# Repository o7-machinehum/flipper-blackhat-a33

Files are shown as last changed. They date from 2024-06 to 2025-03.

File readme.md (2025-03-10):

# Flipper Blackhat A33

The Flipper Blackhat is a Linux based Flipper addon that enables WiFi attacks. It uses an Allwinner A33, which is a quad-core SoC connected to 1Gb of RAM. The board has two USB2 ports, and one USB-C, which is connected to an FTDI.



## TODO (Next Board Rev)

    - [ ] TVS diodes on USB
    - [ ] Reset button
    - [ ] LED
    - [ ] Mounting holes for mech
    - [ ] Cost analasys

## License
The project is licensed under the Creative Commons (4.0 International License) Attribution—Noncommercial—Share Alike license. This allows sharing and adapting material for non-commercial purposes, provided credit is given to the creator and adaptations are shared under the same terms. The material can be used in any format with necessary technical modifications, but no warranties are provided. The license prohibits imposing additional restrictions and ensures the rights are irrevocable as long as the terms are followed.

Make boards for youself, make boards for your friends, but **please do not sell hundreds on them on Aliexpress**. I'm selling boards [here](shop.rootkitlabs.com), the money made here goes back into this project, and other alike open source projects!

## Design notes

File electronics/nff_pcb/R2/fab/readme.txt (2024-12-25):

Flipper Blackhat
--------
Size :	92 x 53
Layer : 4 Layers
Material : FR-4: TG150
Thickness : 1.6 mm
Min track/spacing : 4/4mil
Min hole size : 0.2mm
Solder mask : Black
Silkscreen : White
Edge connector : No
Surface finish : ENIG lead free
Via process : Tenting vias
Finished copper : 1 oz Cu (Inner Copper:1 oz)
Remove product No. : Yes

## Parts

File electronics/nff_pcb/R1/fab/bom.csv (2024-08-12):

Reference | Value | Footprint | Qty | DNP | MPN
C1,C2,C3,C4,C5,C27,C30,C31,C32,C33,C37,C38,C40,C42,C43,C48,C59,C64,C65,C66,C67,C68,C73,C74,C75,C76,C77,C78,C79,C80,C82,C85,C86,C87,C89,C90,C91,C92,C93,C100,C104 | 100nF | Capacitor_SMD:C_0402_1005Metric | 41 |  | CC0402KRX7R7BB104
C6,C9,C10,C11,C14,C15,C16,C17,C22,C23,C24,C25 | 22uF | Capacitor_SMD:C_0805_2012Metric | 12 |  | CL21A226MQQNNNE
C7,C12,C18,C20 | 10nF | Capacitor_SMD:C_0402_1005Metric | 4 |  | CL05B103KB5NNNC
C8,C13 | 450pF | Capacitor_SMD:C_0402_1005Metric | 2 |  | CL05B471KB5NNNC
C19,C21 | 5nF | Capacitor_SMD:C_0402_1005Metric | 2 |  | CC0402KRX7R9BB562
C26,C28 | 10uF | Capacitor_SMD:C_0805_2012Metric | 2 |  | GRM21BR70J106KE76L
C29,C99,C102,C103 | 10uF | Capacitor_SMD:C_0402_1005Metric | 4 |  | CL05A106MQ5NUNC
C34,C49,C50,C101 | 1uF | Capacitor_SMD:C_0402_1005Metric | 4 |  | CL05A105KO5NNNC
C35 | 0.22uF | Capacitor_SMD:C_0603_1608Metric | 1 |  | CC0402KRX7R7BB224
C41,C45,C46,C47 | 10uF | Capacitor_SMD:C_0603_1608Metric | 4 |  | LMK107BBJ106MALT
C53,C54,C55,C56,C69,C70,C94 | 22uF | Capacitor_SMD:C_0402_1005Metric | 7 |  | GRM158R60J226ME01D
C95,C96 | 10pF | Capacitor_SMD:C_0402_1005Metric | 2 |  | CC0402JRNPO9BN100
C97,C98 | 30pF | Capacitor_SMD:C_0402_1005Metric | 2 |  | CC0402JRNPO9BN300
J1 | Micro_SD_Card_Det_Hirose_DM3AT | Connector_Card:microSD_HC_Hirose_DM3AT-SF-PEJM5 | 1 |  | DM3AT-SF-PEJM5
J2,J3 | USB_A | Connector_USB:USB_A_Molex_105057_Vertical | 2 |  | 1050570001
J4 | Conn_01x08_Pin | Connector_PinHeader_2.54mm:PinHeader_1x08_P2.54mm_Horizontal | 1 |  | PH1RB-08-UA
J5 | USB_C_Receptacle_USB2.0_16P | Connector_USB:USB_C_Receptacle_GCT_USB4105-xx-A_16P_TopMnt_Horizontal | 1 |  | USB4105-GF-A-120
J6 | Conn_01x10_Pin | Connector_PinHeader_2.54mm:PinHeader_1x10_P2.54mm_Horizontal | 1 |  | PH1RB-10-UA
J7 | Conn_Coaxial | Connector_Coaxial:SMA_Amphenol_901-143_Horizontal | 1 |  | 901-143-6RFX
J8 | Conn_01x20_MountingPin | Connector_FFC-FPC:Hirose_FH12-20S-0.5SH_1x20-1MP_P0.50mm_Horizontal | 1 |  | FH12-20S-0.5SH(55)
L1,L2,L3,L4 | 1uH | Inductor_SMD:L_Coilcraft_XxL4020 | 4 |  | XAL4020-102ME
L5 | 120R@100MHz | Inductor_SMD:L_0603_1608Metric | 1 |  | BLM18KG121TN1D
L6 | 22uH | Inductor_SMD:L_1210_3225Metric | 1 |  | CBC3225T220MR
R1,R2,R4,R5 | 1k | Resistor_SMD:R_0402_1005Metric | 4 |  | 4-1879208-9
R3,R6 | 240R | Resistor_SMD:R_0402_1005Metric | 2 |  | 0402WGF2400TCE
R7 | 470k | Resistor_SMD:R_0402_1005Metric | 1 |  | RTT024703FTH
R8 | 150k | Resistor_SMD:R_0402_1005Metric | 1 |  | RC0402FR-07150KL
R9 | 330k | Resistor_SMD:R_0402_1005Metric | 1 |  | RC0402FR-07330KL
R10 | 120k | Resistor_SMD:R_0402_1005Metric | 1 |  | RTT021203FTH
R11 | 110k | Resistor_SMD:R_0402_1005Metric | 1 |  | RTT021103FTH
R12 | 160k | Resistor_SMD:R_0402_1005Metric | 1 |  | 0402WGF1603TCE
R13 | 82k | Resistor_SMD:R_0402_1005Metric | 1 |  | 0402WGF8202TCE
R14 | 220k | Resistor_SMD:R_0402_1005Metric | 1 |  | ERJPA2F2203X
R15,R16,R17,R18,R19,R26 | 0R | Resistor_SMD:R_0402_1005Metric | 6 |  | RC0402JR-070RL
R20 | 5R1 | Resistor_SMD:R_0402_1005Metric | 1 |  | RC0402JR-075R1L
R21,R30 | 10k | Resistor_SMD:R_0402_1005Metric | 2 |  | RC0402JR-0710KL
R22,R39 | 10k | Resistor_SMD:R_0402_1005Metric | 2 |  | RC0402FR-1310KL
R23,R24,R25,R41,R42 | 100k | Resistor_SMD:R_0402_1005Metric | 5 |  | RC0402FR-13100KL
R27,R28 | 22R | Resistor_SMD:R_0402_1005Metric | 2 |  | RC0402JR-0722RL
R29,R31 | 10M | Resistor_SMD:R_0402_1005Metric | 2 |  | 0402WGJ0106TCE
R32 | 200k | Resistor_SMD:R_0402_1005Metric | 1 |  | RC0402FR-07200KL
R33,R36 | 1k | Resistor_SMD:R_0402_1005Metric | 2 |  | RC0402FR-131KL
R35 | 0R | Resistor_SMD:R_0402_1005Metric | 1 |  | RC0402FR-130RL
R37 | 100K | Resistor_SMD:R_0402_1005Metric | 1 |  | RC0402FR-13100KL
R43,R44 | 5.6k | Resistor_SMD:R_0402_1005Metric | 2 |  | RC0402FR-135K6L
RN1,RN2 | 10k | Resistor_SMD:R_Array_Convex_4x0402 | 2 |  | 4D02WGJ0103TCE
U1 | AS4C512M16D3L-12BIN | AS4C512M16D3L:Alliance_Memory-AS4C512M16D3L-12BIN-0-0-IPC_A | 1 |  | AS4C512M16D3L-12BIN
U2 | A33 | A33_FP:Allwinner_Technology_Co.,_Ltd.-A33-0 | 1 |  | A33
U3,U4,U5,U6 | TPS62095RGTR | TI:TI_RTE_S-PWQFN-N16 | 4 |  | TPS62095RGTR
U7 | AP131-25 | Package_TO_SOT_SMD:SOT-23-5 | 1 |  | AP131-25
U8 | RTL8723DS | KiLib:RTL8723 | 1 |  | RTL8723DS
U9 | AP3036B | Package_TO_SOT_SMD:SOT-23-6 | 1 |  | AP3036B
U10 | CH340C | Package_SO:SOIC-16_3.9x9.9mm_P1.27mm | 1 |  | CH340C
Y1 | 24Mhz | Crystal:Crystal_SMD_Abracon_ABM8G-4Pin_3.2x2.5mm | 1 |  | ABM8G-24.000MHZ-18-D2Y-T
Y2 | 32.768khz | Abracon:Abracon-ABS05-0-0-MFG | 1 |  | ABS05-32.768KHZ-9-T

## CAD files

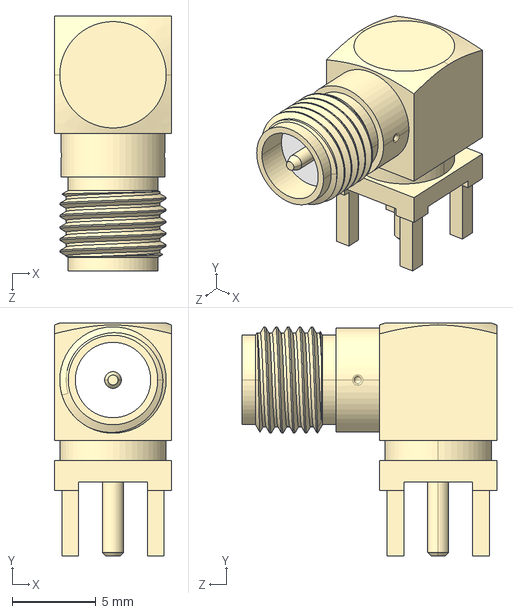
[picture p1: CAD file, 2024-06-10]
electronics/nff_pcb/step/CONREVSMA002-G.step
7.00 x 13.9 x 15.2 mm

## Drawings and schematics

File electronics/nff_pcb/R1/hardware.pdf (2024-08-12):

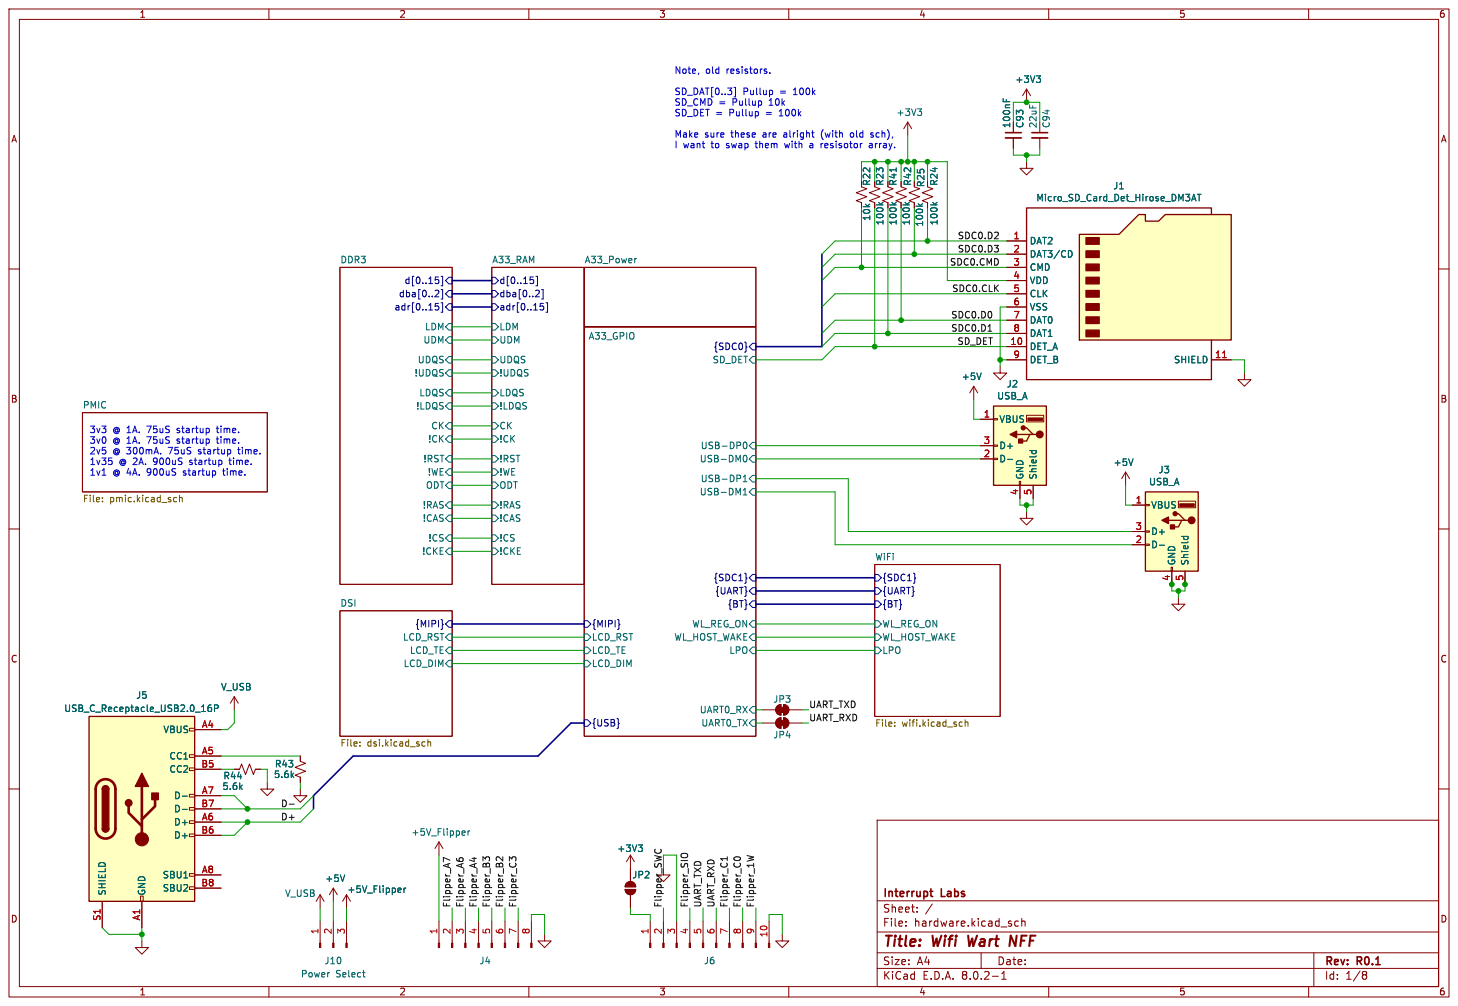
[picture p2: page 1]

{BT} LPO WiFi File: wifi.kicad_sch

File: hardware.kicad_sch Sheet: /
Id: 1/8 Title: Wifi Wart NFF

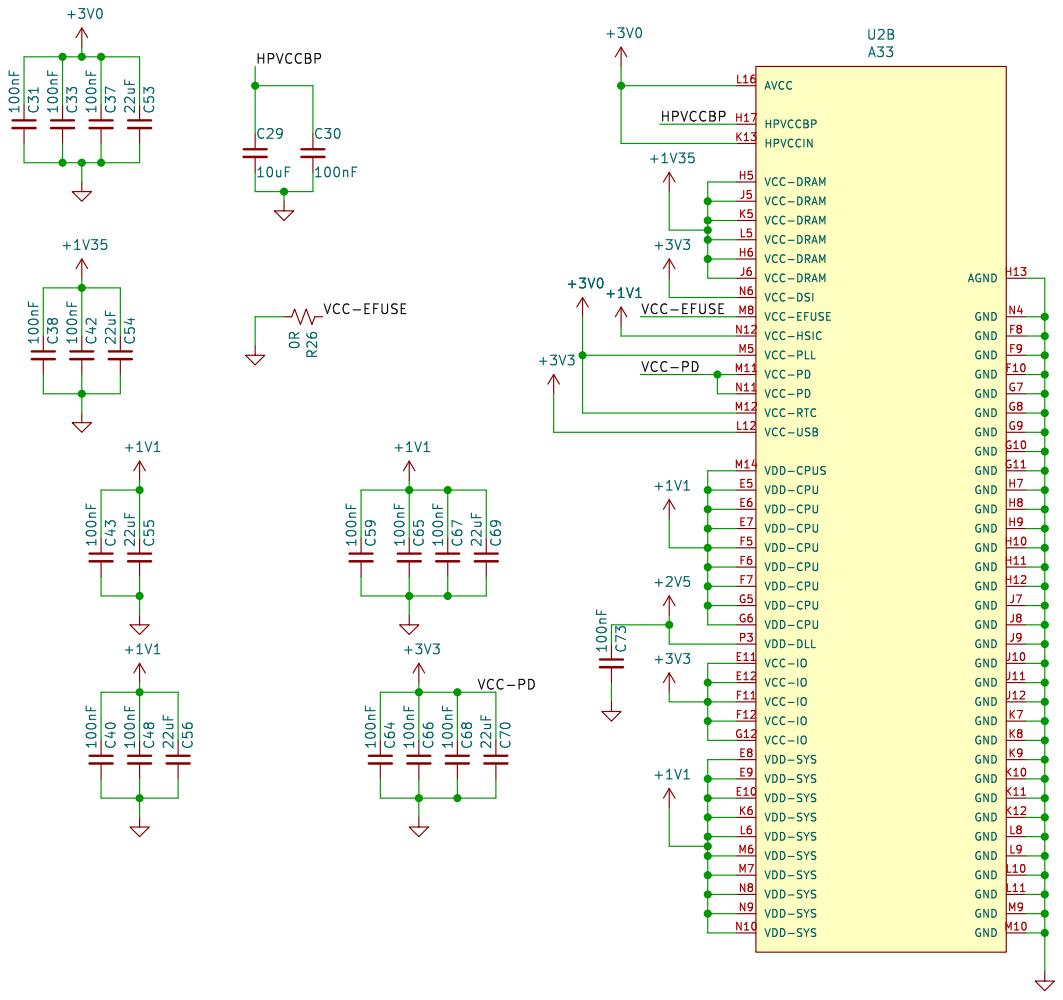
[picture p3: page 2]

File: a33_power.kicad_sch Sheet: /A33_Power/
Id: 2/8 Title: Wifi Wart NFF

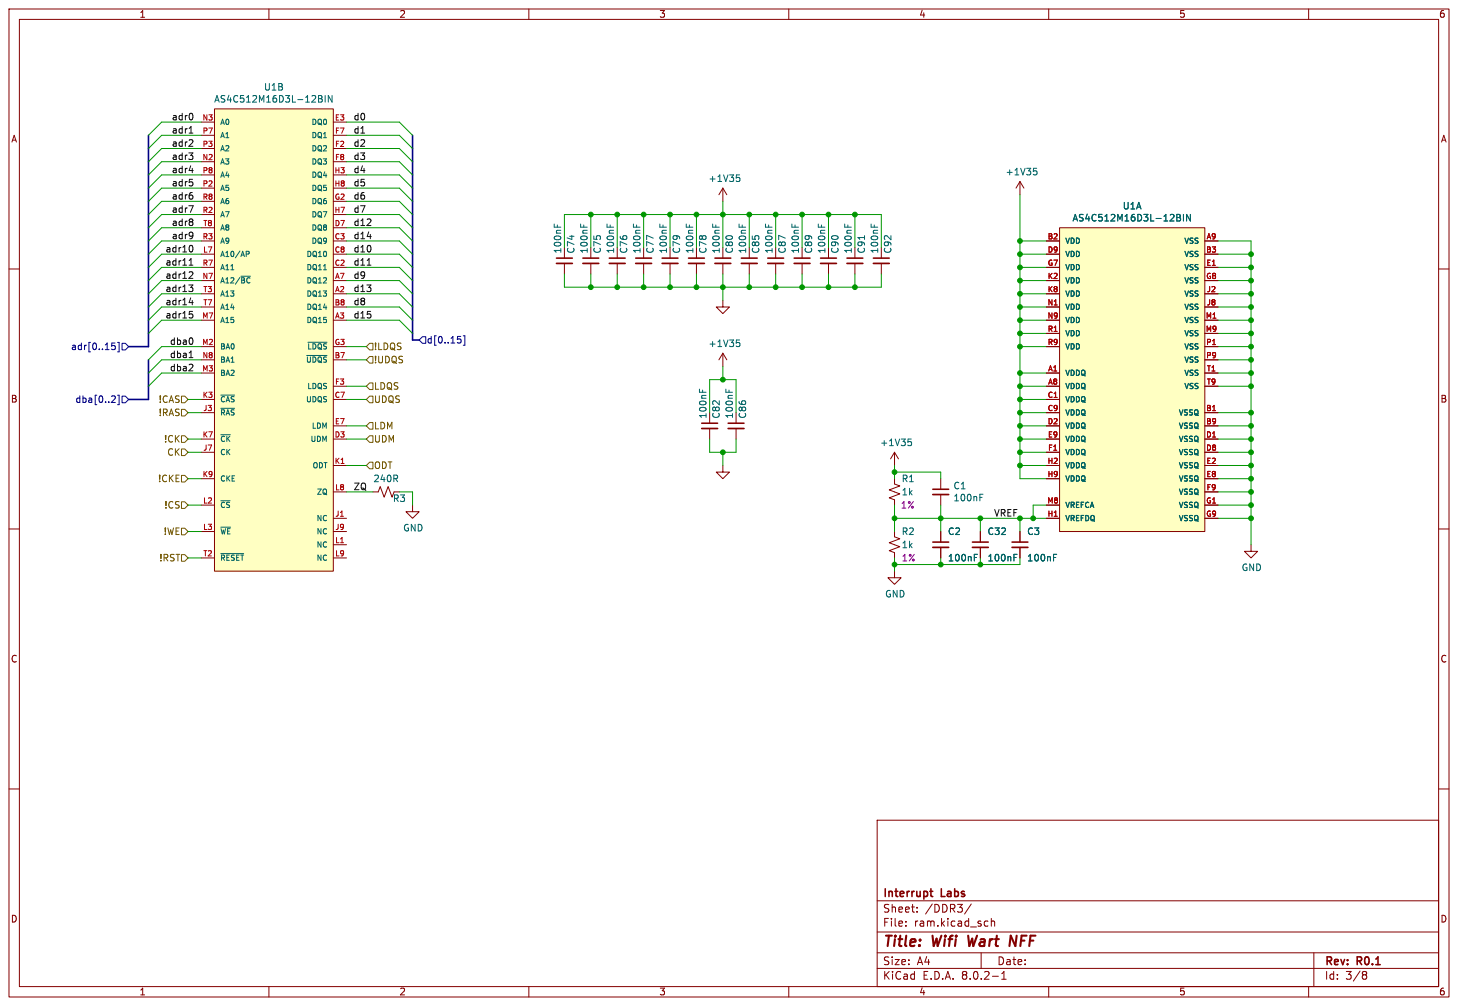
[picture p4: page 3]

File: ram.kicad_sch Sheet: /DDR3/
Id: 3/8 Title: Wifi Wart NFF

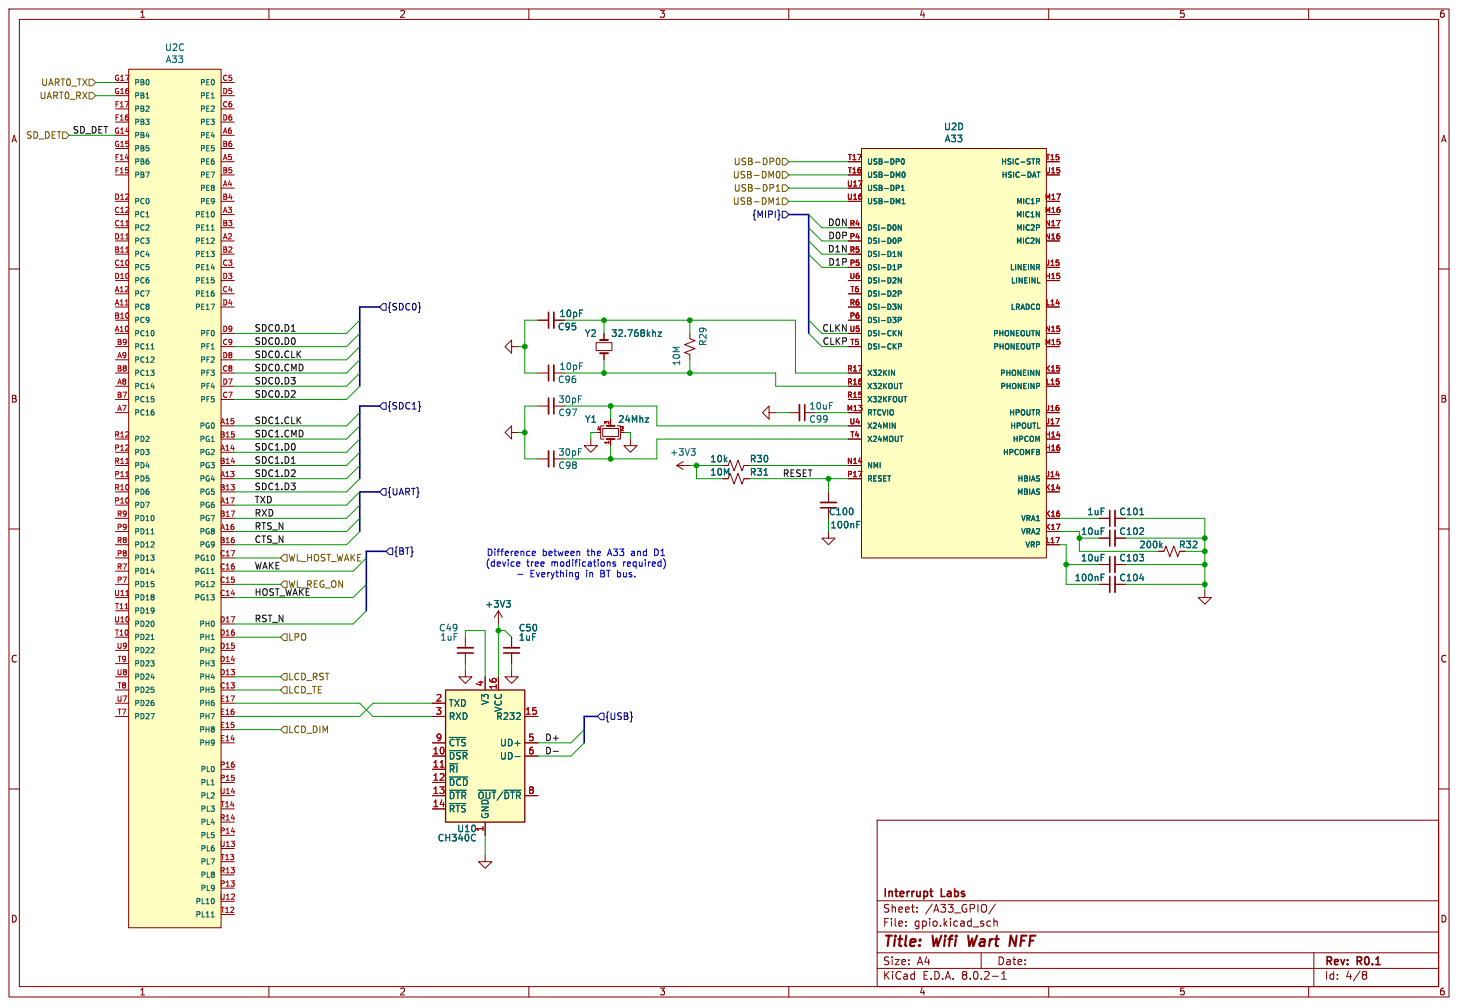
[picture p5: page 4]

File: gpio.kicad_sch Sheet: /A33_GPIO/
Id: 4/8 Title: Wifi Wart NFF

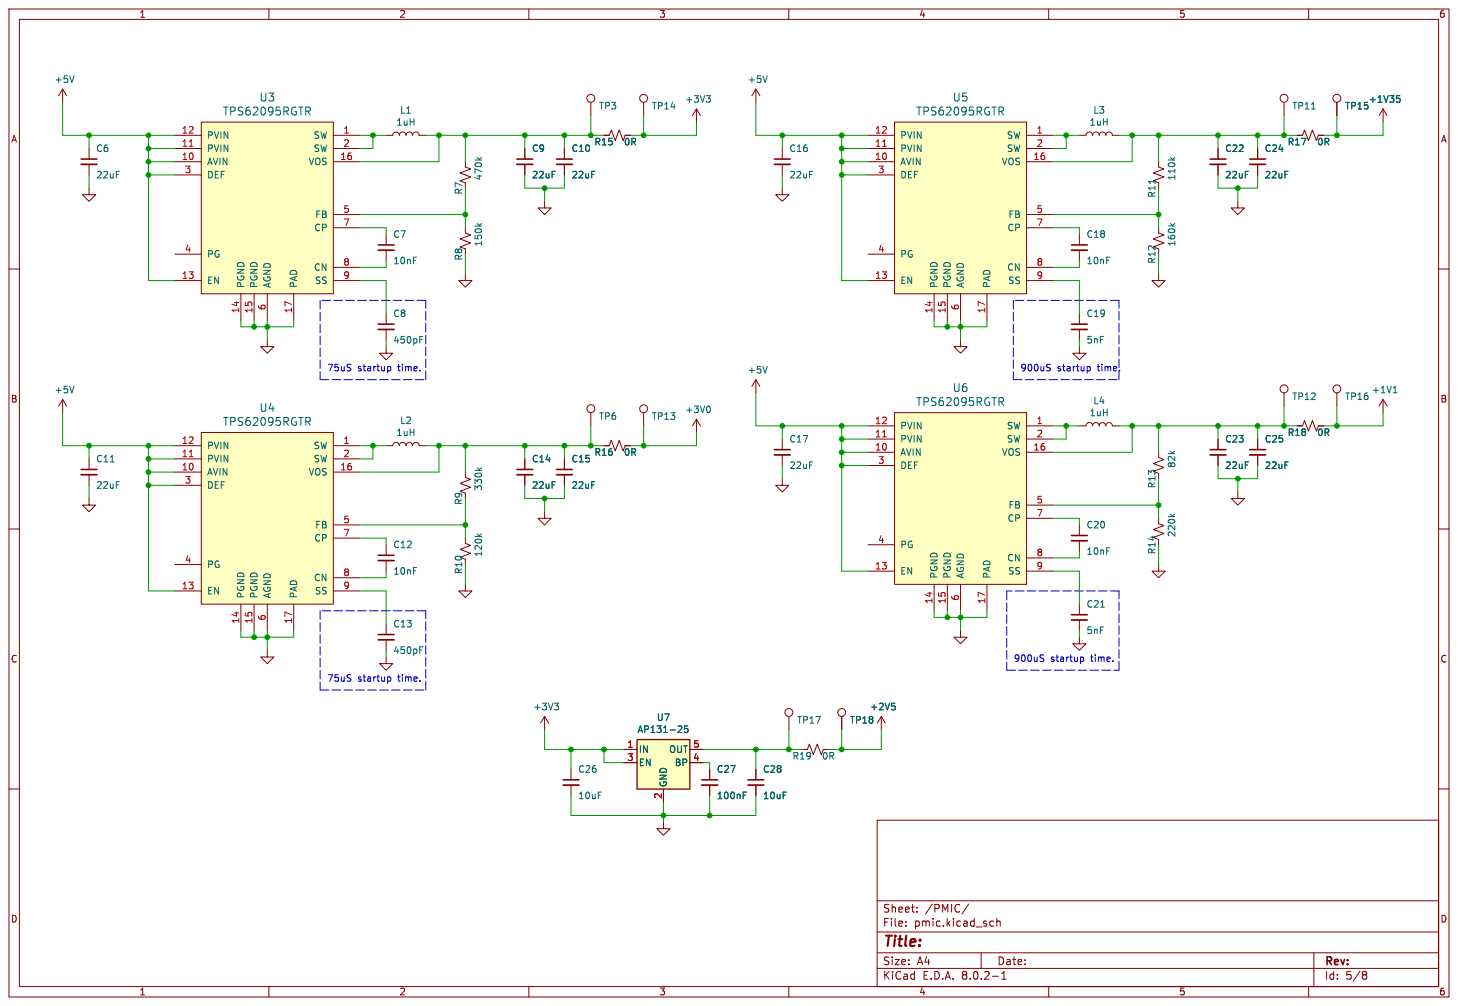
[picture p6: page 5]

Id: 5/8 Title: File: pmic.kicad_sch Sheet: /PMIC/

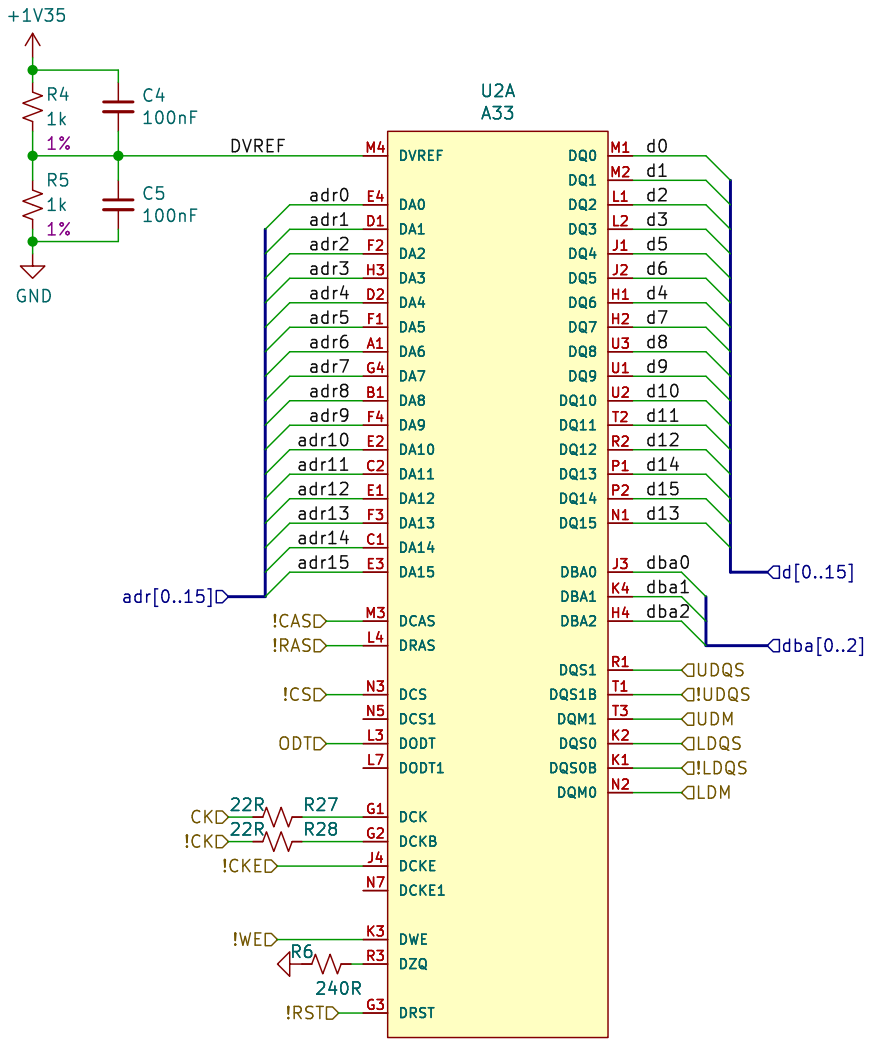
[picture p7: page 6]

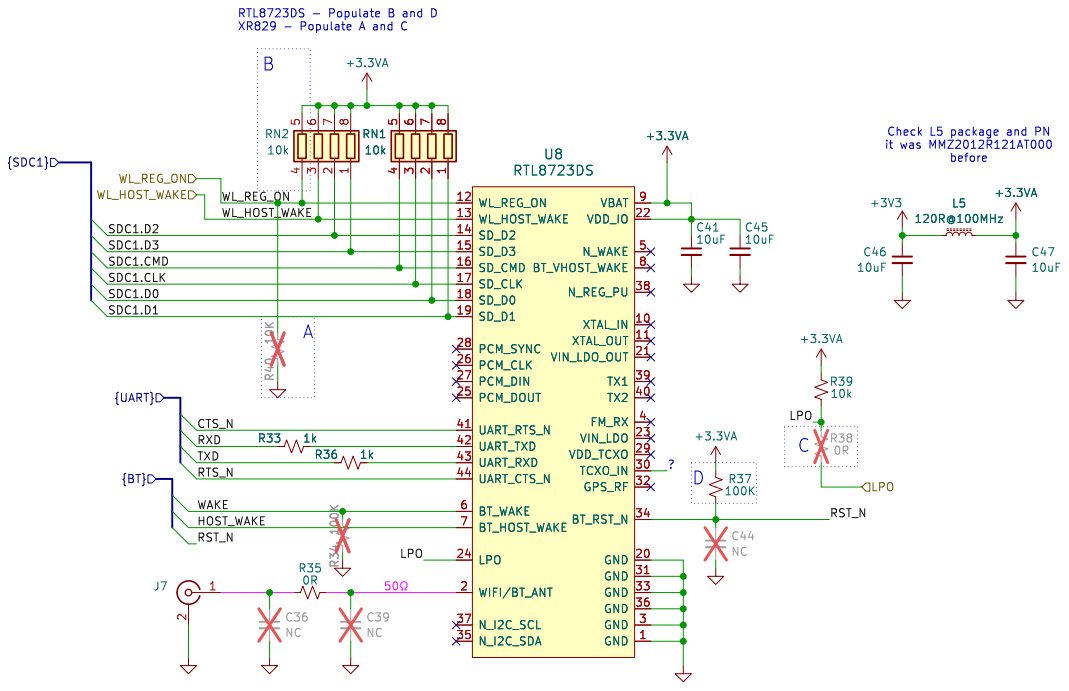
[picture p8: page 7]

Check L5 package and PN
it was MMZ2012R121AT000

Id: 7/8 Title: File: wifi.kicad_sch Sheet: /WiFi/

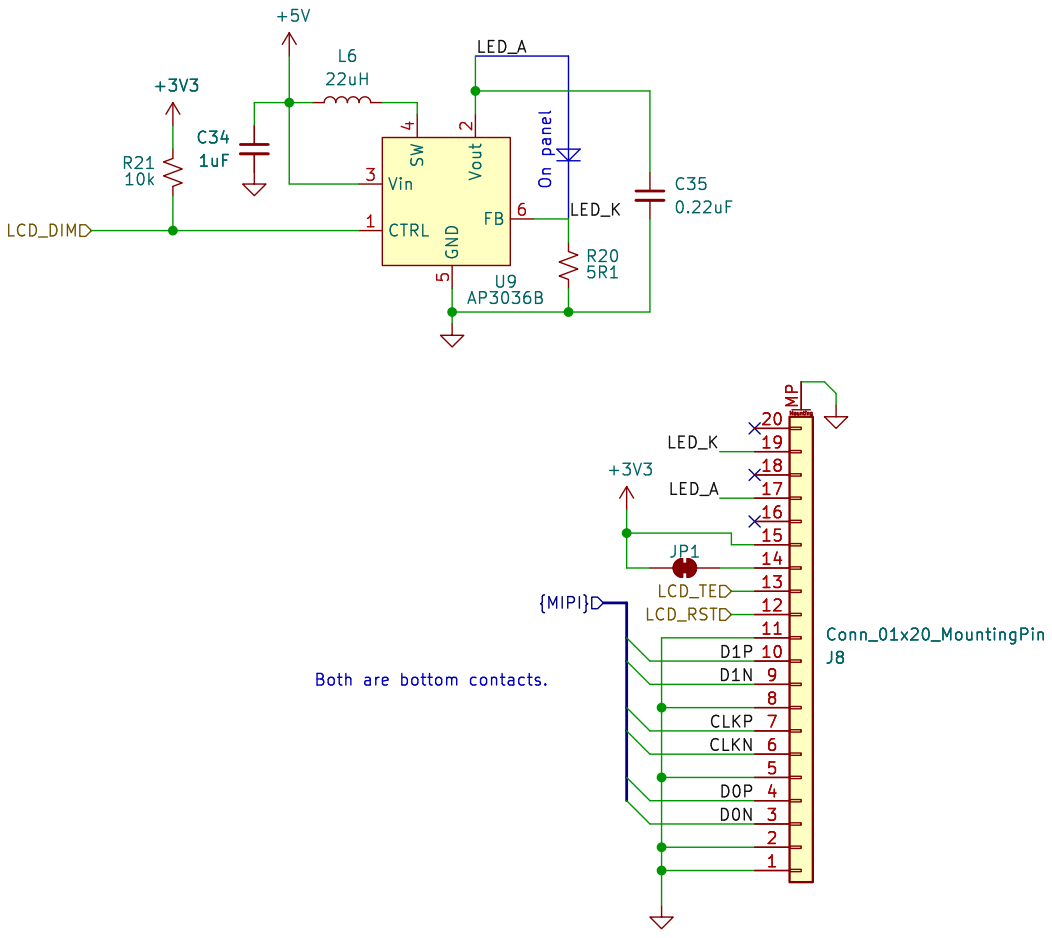
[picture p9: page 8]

D1P On panel Both are bottom contacts. +3V3 C34

Id: 8/8 Title: File: dsi.kicad_sch Sheet: /DSI/

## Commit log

2024-06-10 Removed quite a bit.
    [1050570001.stp, 36911000000.FCStd, 36911000000.step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]
2024-08-12 R0.1 released.
    [a33_power.kicad_sch, a33_ram.kicad_sch, bom.csv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]
2024-08-30 Removed legacy kicad files.
    [a33_power.sch, gpio.sch, hardware.sch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]
2024-10-04 Added the proper SMA conntector
    [CONREVSMA002-G.step, wifi.kicad_sch]
2024-12-03 “or” the 5V line, “or” the UART bus, reroute the PWM line to be actually PWM, Reset button., Decoup caps over USB.
    [gpio.kicad_sch, hardware.kicad_sch, pmic.kicad_sch]
2024-12-25 R2 Released
    [gpio.kicad_sch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]
